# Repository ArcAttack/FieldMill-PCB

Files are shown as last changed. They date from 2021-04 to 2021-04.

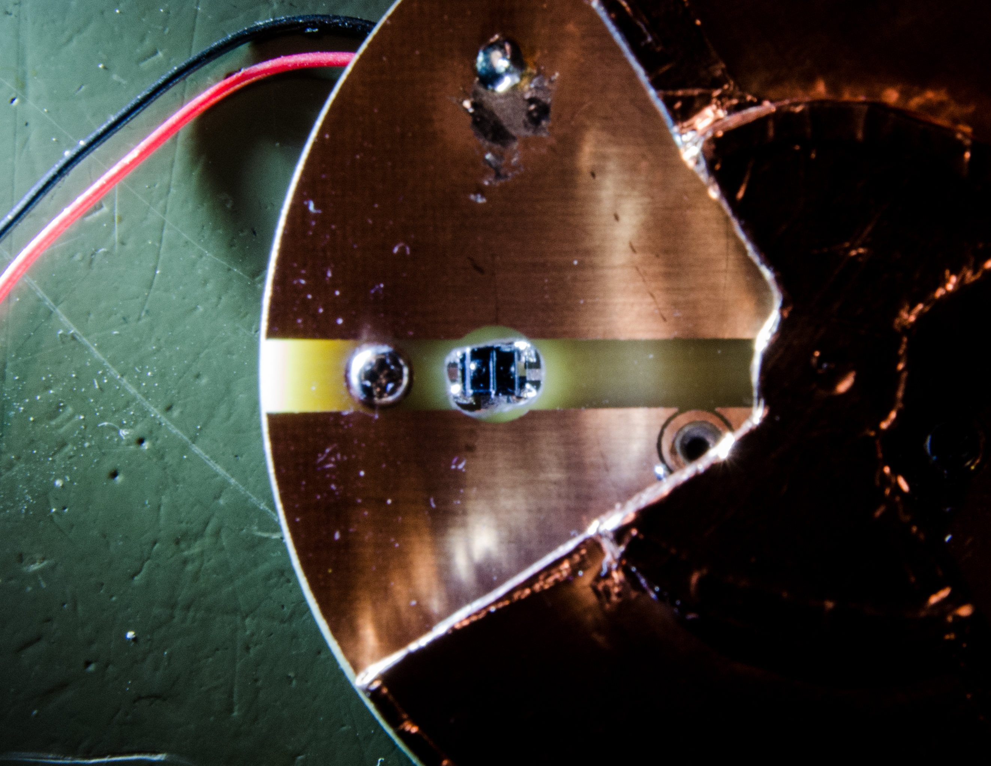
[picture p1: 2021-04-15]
Pictures/Image-4.jpg

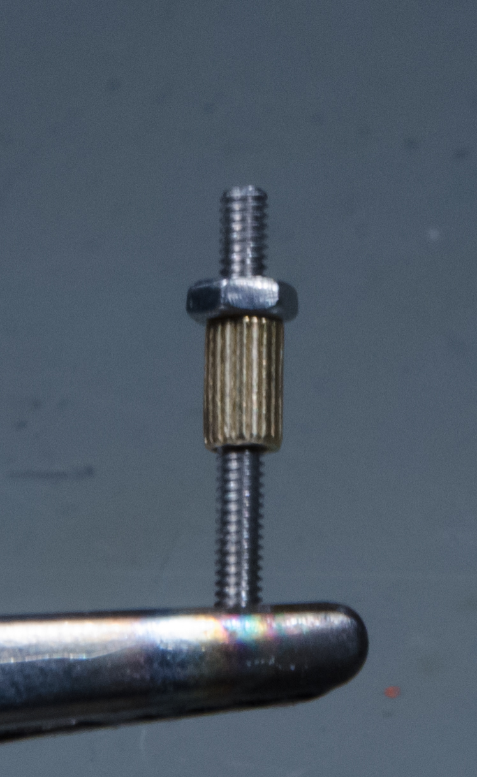
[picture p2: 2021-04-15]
Pictures/Image-7.jpg

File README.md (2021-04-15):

# FieldMill PCB Files
This is the Repo for the hardware associated with our Fieldmill project [link TBD]

# A short guide of how to make one yourself
### Component procurement. You'll need the following:

  - The PCBs: 
   
    There are exported gerbers packaged into .rar archives in the Gerber/V[number] folder, all four are needed. You can order these from whatever PCB manufacturer you prefer or make them yourself
    They are all single layer* and I have made the demo mill with home-etched pcbs too.
    (JLC would charge ~11€ plus shipping for all required PCBs as of April 2021)
    
    *The stator and rotor are double layer but have no structures on the bottom one. The rotor just needs to be cut from double sided base material. The stator boards needs to have the holes connecting the four electrodes (the ones that are in the middle of them) slightly counter-sunk on the bottom side to prevent shorting against the back plane.
    
  - The Components: 
  
    You will need approximately 25€ worth of components. Almost all smd parts, but non smaller than 0805. 
    I have created a ready to import bom document for DigiKey ("Full BOM - DigiKey.xlsx"). Simply import it to your card with the "Upload a File" Tab above the manual part adding box on the top of the page. You can ignore the warning about better options and just hit the submit button if it warns you about that.
    
    __IMPORTANT__ the ESP32 dev kit is not included in the BOM, you will need to find it somewhere else. Doesn't need to be anything special and you'll probably find it on any of the common websites (aliexpress, amazon, ebay...)
    You will also need a set of M2 (or comparable imperial size) standoffs and screws (four a few mm long plus four >20mm ones that get cut apart) to mount the boards together, I used some from a multi box set from amazon but anything that is kind of the right size will work.
    
### Assembly.

1.  Assemble the individual PCBs. (check out the Pictures folder for some reference images showing how it should look and which side the components go onto)
    
    If you have never soldered SMD parts before I recommend watching some of the how to videos about it on youtube. Don't worry it's really not that hard :) (just remember: you can't ever have too much flux ;) )
    The component values should all be marked on the silkscreen, but if I forgot any or you made the board at home you can always look at the parts list in the PDF docs ("ESP32 Board.PDF" and "Front End.PDF")
    
    **IMPORTANT** make sure to clean the front-end board VERY THOROUGHLY with a brush and IPA or ethanol after assembly. Even the slightest residue will cause leakages that ruin the Sensor
   
2.  Prepare the case. 

    The STL files for this are in the "3D Models" Folder. There are four pieces that need to be made. The precision does not need to be very high (I had a friend print this on a 5 year old filament printer with no issues).
    If the screw threads on the middle part don't quite work out you can use a bit of sand paper or a file to get them to fit.
    
    Then you will need to cover the top part (the one that has no closed ends) in copper tape or something else conductive to prevent charges building up on it and ruining the readings. 
    You will also need to cover one half of the middle part, specifically the one where the sensor fits. To figure out which one that is you should check on which side the header on the front end board lines up with the hole in hte center part. 
    
    After you've done that you should screw the top and middle parts together (maybe even glue them with a bit of CA glue) and tape across the gap on the inside to electrically connect them (make sure you test this with a multimeter!). (It should look like Image-2.jpg after this)
    
3.  Assemble the sensor. (to see on which side things should go look at Image-5.jpg)

    Start off by screwing the motor and four male-female 5mm standoffs to the stator board (the standoffs go into the four outer holes). The parts all go onto the side that has the exposed pad in the middle.
    
    Then solder some single header pins onto the pads facing the same diretion as the motor does, and push the front end board onto it. The 8 pin header on it should face away from the stator.
    **IMPORTANT** make sure that the optical sensor (IC2) is located underneath the slot in the stator board (as Image-4.jpg shows) or the mill will not work!
    
    Next you can solder the pins to the front end board (make sure it is sitting flat), and screw some female-female 10mm standoffs onto the threads of the standoffs from the previos step to hold the PCB in place.
    
    To screw the assembly into the case you need to cut 20mm pieces off of an M2 threaded rod (or a long screw) and screw them through some female-female 5mm standoffs (compare Image-7.jpg, the nut is to allow screwing it in with a screwdriver). It should go inside the copper coverd side of the case we made before.
    Before you screw it in you should make sure that the motor wires are pulled through the hole in the center part and pin header on the front end board is located over it (as in Image-6.jpg) so the ESP board can be connected to it in the next step. 
    
    Now you need to ground the motor shaft, which we do with the spring pluger. If your screw take solder you can just solder it right onto them like you see in Picture-5.jpg. If they don't you can take a male-female standoff and use a file or some rough sandpaper to make it ~0.5mm tall and then solder onto that (thats the way I did it). I also used a triangular file to cut a little vertical groove into the plunger to give it some larger contact area, but I'm not sure if that really does much. You might also want to add a tiny dab of lithium grease to the shaft after this to reduce friction and wear.
    
    We also need to make the rotor. To mount it on the shaft and electrically connect the two you'll need the hub from the 3D Models folder: solder a ~0.4mm wire into the small off-center hole on the rotor, pull it through the hub and glue the hub down onto the rotor PCB. Make sure that you orient the hub so the wire can go into the little groove in the side of it. Just press fit it onto the shaft and make sure it is sitting sort of square (best seen when looking at it from the side and turning it).
    
    **IMPORTANT** If you made these boards yourself or you ordered them with gold plating you might need to cover the bottom of the Rotor (the exposed side) with aluminium tape, as the opto-interrupter might not get enough signal otherwise.
    
    Finally you have to push the ESP32 board onto the back of what we just made (should look like Image-9.jpg), so it connects with the pins on the front end, and screw it on with either some more f-f m2 standoffs (no longer than 10mm though) or just some m2 washers. You might have to cut the pin header down a bit though, the one I found on digikey is not the same lengh as the one I used.
    To access the USB port you'll need to leave the bottom cover off, but once the code is programmed you can close that and only need access to the power input, which should line up with the hole in the side.
    
### Software 
  
  To programm the ESP you should follow the steps detailed in the firmware repo: https://github.com/ArcAttack/FieldMill-Firmware
  
### Profit
    
That's it :) If you have any questions feel free to contact us on our website and we look forward to hearing your feedback.
    
# Notes

VIn needs to be between 6V and 24V, the mill can also run from just USB.

To connect the motor you can either solder in the wire directly or use some JST XH connectors. You can buy those in kits too, just look for XH connector set on the internet and you'll find them. The wires from the motor are so small that you might have to solder them into the crimp-contacts though.

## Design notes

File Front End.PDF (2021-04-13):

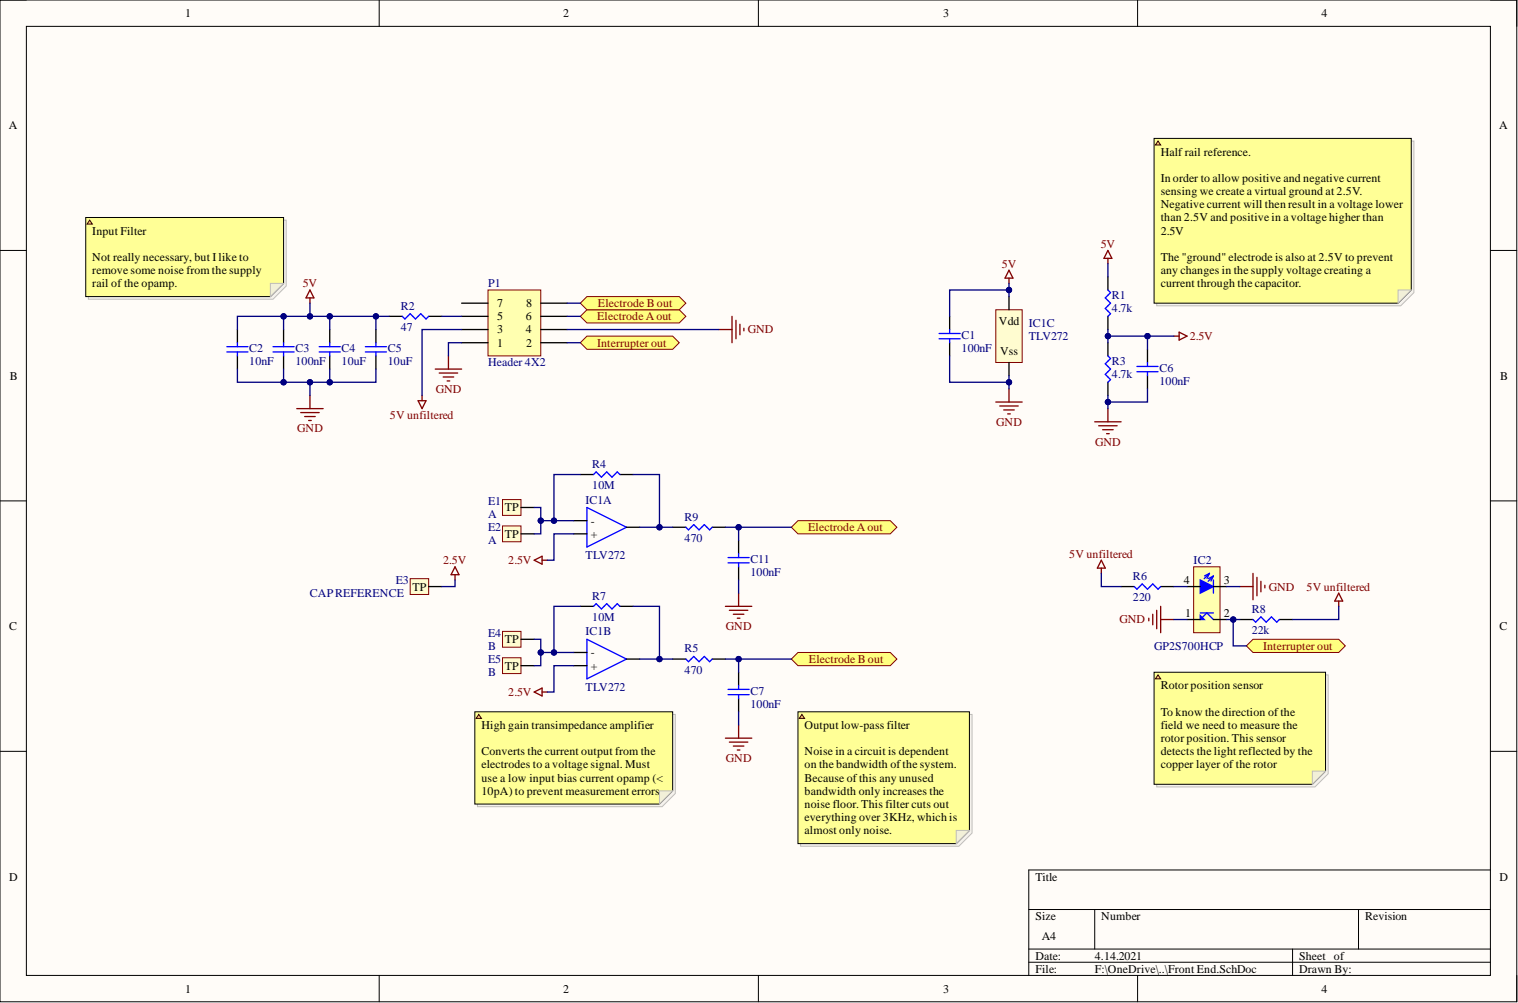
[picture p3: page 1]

Line # | Name | Description | Designator | Quantity | TargetPrice | Manufacturer 1 | Manufacturer Part Number 1 | Manufacturer Lifecycle 1 | Supplier 1 | Supplier Part Number 1 | Supplier Unit Price 1 | Supplier Subtotal 1
| 100nF | | C1, C3, C6, C7, C11 | 5 | 0 KEMET | | C0402C104K8PACTU | Volume Production | Digi-Key | 399-3027-1-ND | 0,042 | 0,42
| 10nF | | C2 | 1 | 0 Samsung | | CL21B103KBANNNC | Volume Production | Digi-Key | 1276-1015-1-ND | 0,1 | 0,1
| 10uF | | C4, C5 | 2 | 0 Murata | | GRM188R60J106ME47D | Volume Production | Digi-Key | 490-3896-1-ND | 0,25 | 0,5
| A | | E1, E2 | 2 | 0
| CAP REFERENCE | | E3 | 1 | 0
| B | | E4, E5 | 2 | 0
| TLV272 | | IC1 | 1 | 0,99 Texas Instruments | | TLV272IDR | Volume Production | Digi-Key | 296-10655-1-ND | 0,99 | 0,99
| 4.7k | | R1, R3 | 2 | 0 Yageo | | RT0805FRE074K7L | Not Recommended for New Design | Digi-Key | YAG3364CT-ND | 0,1 | 0,2
| 47 | | R2 | 1 | 0 Yageo | | RC0805JR-0747RL | Volume Production | Digi-Key | 311-47ARCT-ND | 0,1 | 0,1
| 10M | | R4, R7 | 2 | 0 Yageo | | RC0805JR-0710ML | Volume Production | Digi-Key | 311-10MARCT-ND | 0,1 | 0,2
| 470 | | R5, R9 | 2 | 0 Yageo | | RC0805JR-07470RL | Volume Production | Digi-Key | 311-470ARCT-ND | 0,1 | 0,2
| 220 | | R6 | 1 | 0 Yageo | | RC0805FR-07220RL | Volume Production | Digi-Key | 311-220CRCT-ND | 0,1 | 0,1
| 22k | | R8 | 1 | 0 Yageo | | RC0805FR-0722KL | Volume Production | Digi-Key | 311-22.0KCRCT-ND | 0,1 | 0,1
| Header 4X2 | Header, 4-Pin, Dual row | P1 | 1 | 0
| GP2S700HCP | Optical reflection interrupter | IC2 | 1 | 0 Socle Technology | | GP2S700HCP | Unknown | Digi-Key | 1855-1020-1-ND | 1,71 | 1,71

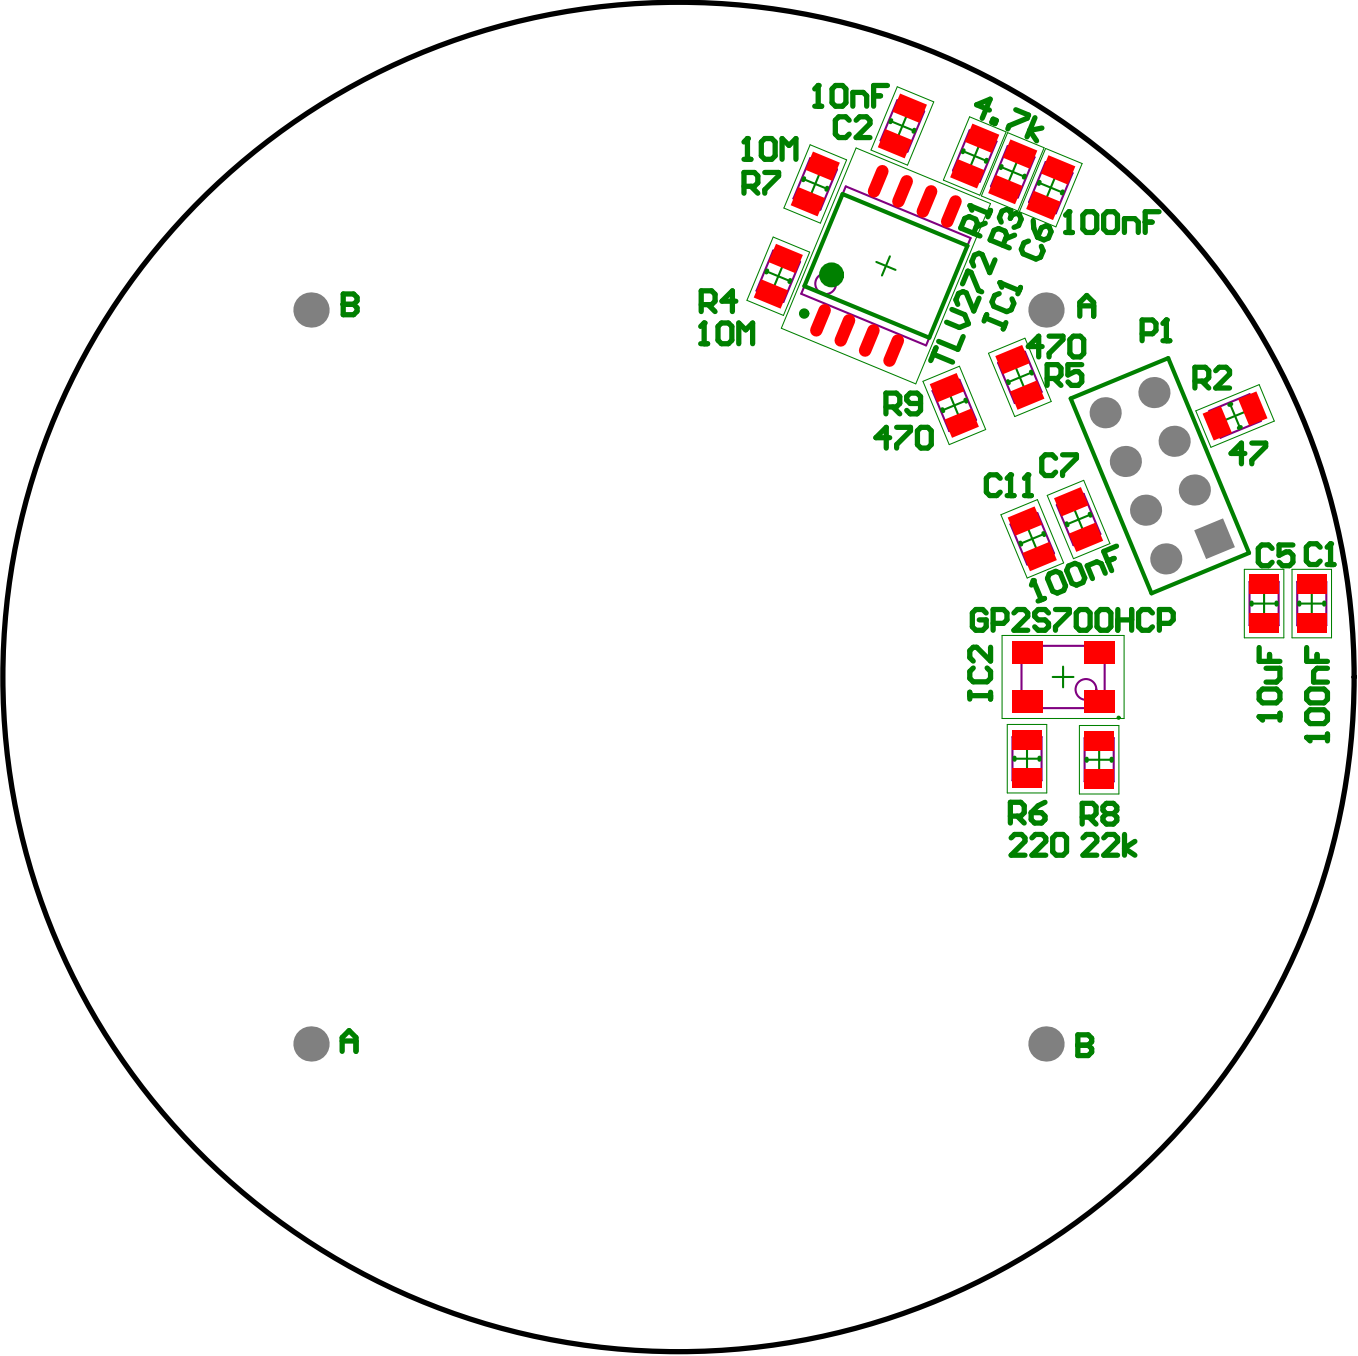
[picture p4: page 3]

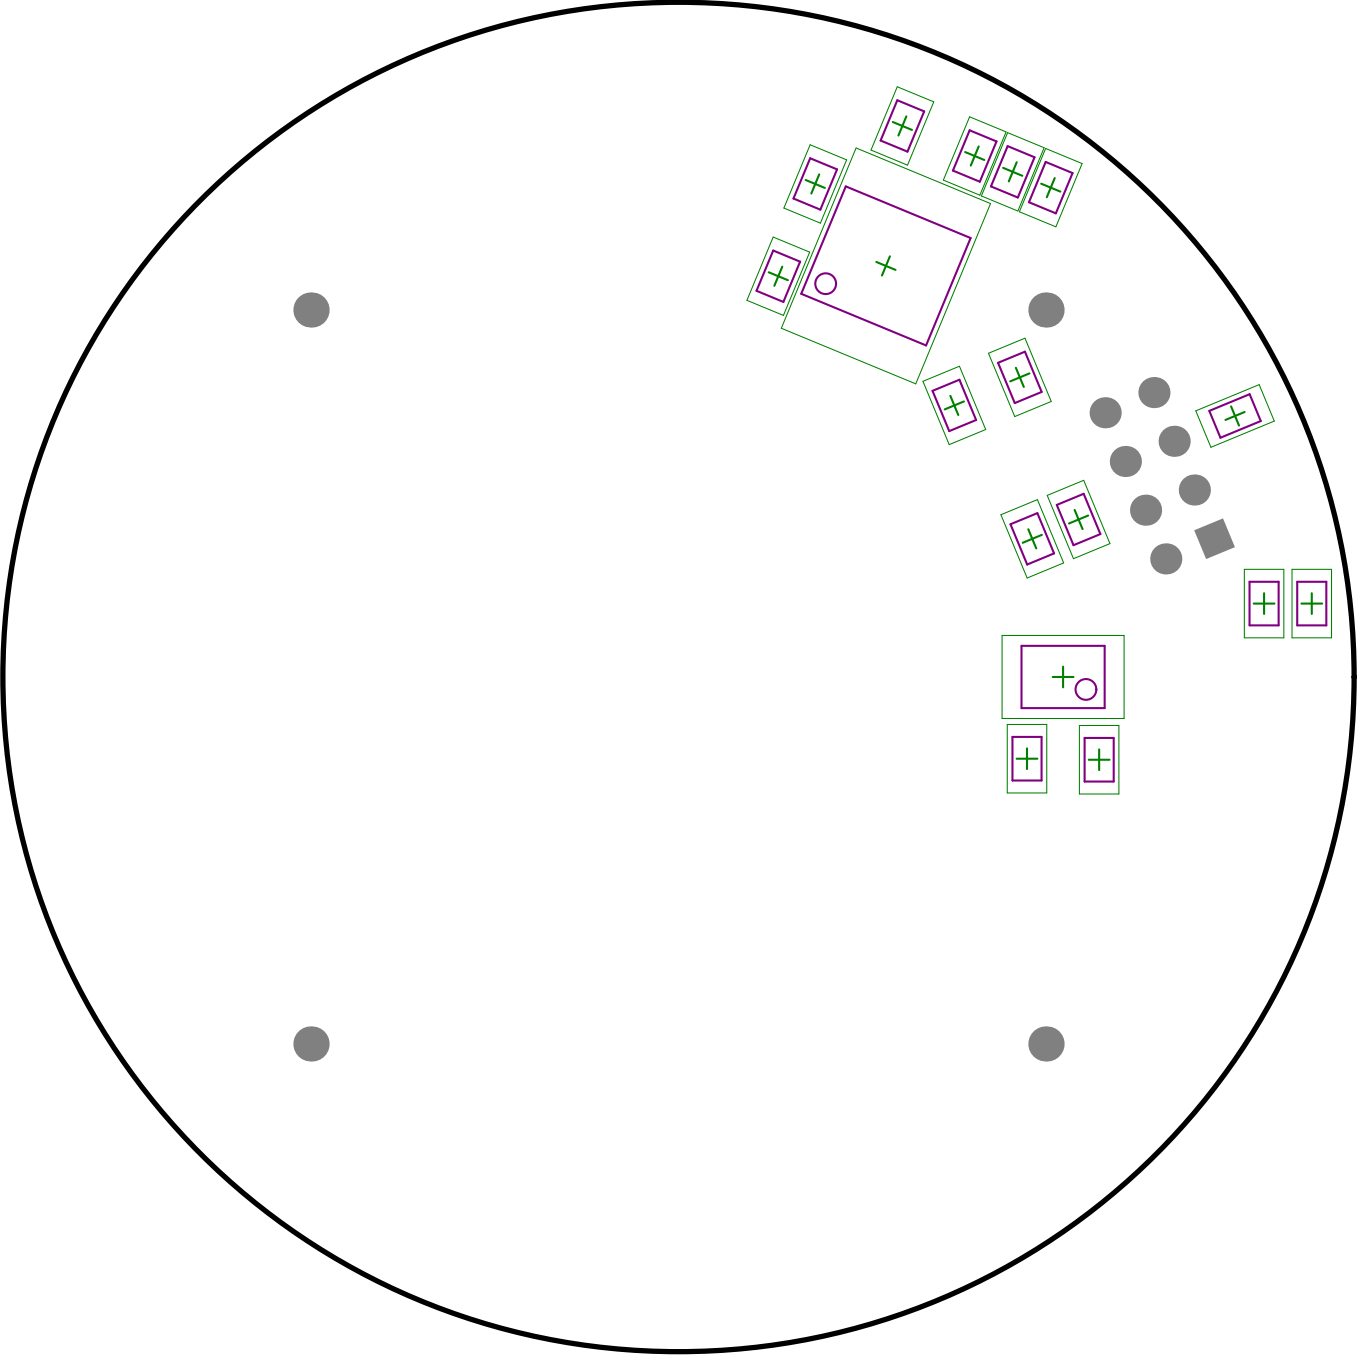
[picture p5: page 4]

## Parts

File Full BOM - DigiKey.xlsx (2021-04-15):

Manufacturer Part Number | Manufacturer | Digi-Key Part Number | Customer Reference | Reference Designator | Packaging | Part Status | Quantity | Unit Price | Extended Price | Quantity Available | Mfg Std Lead Time | Description | RoHS Status | Lead Free Status | REACH Status
CL21B104KACNNNC | Samsung Electro-Mechanics | 1276-1099-1-ND |  |  | Cut Tape (CT) | Active | 6 | 0,09000 | 0,54 € | 278128 | 28 Weeks | CAP CER 0.1UF 25V X7R 0805 | ROHS3 Compliant | Lead free | REACH Unaffected
ESH337M035AH1AA | KEMET | 399-6581-ND |  |  | Bulk | Active | 1 | 0,35000 | 0,35 € | 3671 | 24 Weeks | CAP ALUM 330UF 20% 35V RADIAL | ROHS3 Compliant | Lead free | REACH Unaffected
CL21B102KBANNNC | Samsung Electro-Mechanics | 1276-1020-1-ND |  |  | Cut Tape (CT) | Active | 2 | 0,09000 | 0,18 € | 313296 | 28 Weeks | CAP CER 1000PF 50V X7R 0805 | ROHS3 Compliant | Lead free | REACH Unaffected
CL21A106KAYNNNG | Samsung Electro-Mechanics | 1276-6454-1-ND |  |  | Cut Tape (CT) | Active | 2 | 0,18000 | 0,36 € | 277384 | 28 Weeks | CAP CER 10UF 25V X5R 0805 | ROHS3 Compliant | Lead free | REACH Unaffected
B130-13-F | Diodes Incorporated | B130-FDICT-ND |  |  | Cut Tape (CT) | Active | 3 | 0,31000 | 0,93 € | 148532 | 18 Weeks | DIODE SCHOTTKY 30V 1A SMA | ROHS3 Compliant | Contains lead | REACH Affected
LG R971-KN-1 | OSRAM Opto Semiconductors Inc. | 475-1410-1-ND |  |  | Cut Tape (CT) | Active | 1 | 0,22000 | 0,22 € | 324582 | 12 Weeks | LED GREEN DIFFUSED 0805 SMD | ROHS3 Compliant | Lead free | REACH Unaffected
150060GS75000 | Würth Elektronik | 732-4971-1-ND |  |  | Cut Tape (CT) | Active | 3 | 0,12000 | 0,36 € | 93911 | 10 Weeks | LED GREEN CLEAR 0603 SMD | ROHS3 Compliant | Lead free | REACH Unaffected
ADR02ARZ | Analog Devices Inc. | ADR02ARZ-ND |  |  | Tube | Active | 1 | 2,58000 | 2,58 € | 1936 | 28 Weeks | IC VREF SERIES 0.1% 8SOIC | ROHS3 Compliant | Lead free | REACH Unaffected
MCP3301-BI/SN | Microchip Technology | MCP3301-BI/SN-ND |  |  | Tube | Active | 1 | 2,49000 | 2,49 € | 2419 | 45 Weeks | IC ADC 13BIT SAR 8SOIC | ROHS3 Compliant | Lead free | REACH Unaffected
PJ-082BH | CUI Devices | CP-082BHCT-ND |  |  | Cut Tape (CT) | Active | 1 | 1,46000 | 1,46 € | 27481 | 11 Weeks | CONN PWR JACK 2.5X5.5MM SOLDER | RoHS Compliant | Lead free | Not Available
LQH43PN470M26L | Murata Electronics | 490-12050-1-ND |  |  | Cut Tape (CT) | Active | 1 | 0,34000 | 0,34 € | 4114 | 19 Weeks | FIXED IND 47UH 520MA 861.6 MOHM | ROHS3 Compliant | Lead free | Not Available
2546 | Kitronik Ltd. | 1927-1023-ND |  |  | Bag | Active | 1 | 1,35000 | 1,35 € | 88 | 4 Weeks | MOTOR LO INERTIA 1820 RPM 0.5-3V | Not Available | Not Available | Not Available
T2N7002AK,LM | Toshiba Semiconductor and Storage | T2N7002AKLMCT-ND |  |  | Cut Tape (CT) | Active | 1 | 0,14000 | 0,14 € | 28842 | 16 Weeks | MOSFET N-CH 60V 200MA SOT23 | RoHS Compliant | Lead free | Not Available
RC0805JR-072K2L | Yageo | 311-2.2KARCT-ND |  |  | Cut Tape (CT) | Active | 1 | 0,09000 | 0,09 € | 103703 | 20 Weeks | RES SMD 2.2K OHM 5% 1/8W 0805 | ROHS3 Compliant | Lead free | REACH Unaffected
RT0805FRE074K7L | Yageo | YAG3364CT-ND |  |  | Cut Tape (CT) | Active | 3 | 0,09000 | 0,27 € | 14055 | 20 Weeks | RES SMD 4.7K OHM 1% 1/8W 0805 | ROHS3 Compliant | Lead free | REACH Unaffected
RC0805FR-07220RL | Yageo | 311-220CRCT-ND |  |  | Cut Tape (CT) | Active | 5 | 0,09000 | 0,45 € | 61879 | 20 Weeks | RES SMD 220 OHM 1% 1/8W 0805 | ROHS3 Compliant | Lead free | REACH Unaffected
RC0805FR-07100RL | Yageo | 311-100CRCT-ND |  |  | Cut Tape (CT) | Active | 1 | 0,09000 | 0,09 € | 2632504 | 20 Weeks | RES SMD 100 OHM 1% 1/8W 0805 | ROHS3 Compliant | Lead free | REACH Unaffected
RC0805FR-071KP | Yageo | YAG1321DKR-ND |  |  | Digi-Reel | Active | 1 | 5,59000 | 5,59 € | 19807 | 20 Weeks | RES SMD 1K OHM 1% 1/8W 0805 | ROHS3 Compliant | Lead free | REACH Unaffected
RC0805JR-071K2L | Yageo | 311-1.2KARDKR-ND |  |  | Digi-Reel | Active | 1 | 5,59000 | 5,59 € | 446839 | 20 Weeks | RES SMD 1.2K OHM 5% 1/8W 0805 | ROHS3 Compliant | Lead free | REACH Unaffected
RC0805JR-07300RL | Yageo | 311-300ARCT-ND |  |  | Cut Tape (CT) | Active | 1 | 0,09000 | 0,09 € | 258469 | 20 Weeks | RES SMD 300 OHM 5% 1/8W 0805 | ROHS3 Compliant | Lead free | REACH Unaffected
AP1509-50SG-13 | Diodes Incorporated | AP1509-50SGDICT-ND |  |  | Cut Tape (CT) | Active | 1 | 1,18000 | 1,18 € | 10541 | 36 Weeks | IC REG BUCK 5V 2A 8SOP | ROHS3 Compliant | Lead free | REACH Unaffected
C0402C104K8PACTU | KEMET | 399-3027-1-ND |  |  | Cut Tape (CT) | Active | 5 | 0,09000 | 0,45 € | 1668876 | 37 Weeks | CAP CER 0.1UF 10V X5R 0402 | ROHS3 Compliant | Lead free | REACH Unaffected
CL21B103KBANNNC | Samsung Electro-Mechanics | 1276-1015-1-ND |  |  | Cut Tape (CT) | Active | 3 | 0,09000 | 0,27 € | 989993 | 28 Weeks | CAP CER 10000PF 50V X7R 0805 | ROHS3 Compliant | Lead free | REACH Unaffected
GRM188R60J106ME47D | Murata Electronics | 490-3896-1-ND |  |  | Cut Tape (CT) | Active | 2 | 0,21000 | 0,42 € | 138681 | 23 Weeks | CAP CER 10UF 6.3V X5R 0603 | ROHS3 Compliant | Lead free | Not Available
TLV272IDR | Texas Instruments | 296-10655-1-ND |  |  | Cut Tape (CT) | Active | 1 | 0,84000 | 0,84 € | 0 | 35 Weeks | IC CMOS 2 CIRCUIT 8SOIC | ROHS3 Compliant | Lead free | REACH Unaffected
GP2S700HCP | SHARP/Socle Technology | 1855-1020-1-ND |  |  | Cut Tape (CT) | Active | 1 | 1,46000 | 1,46 € | 0 | 19 Weeks | PHOTOINTERRUPTER REFLEC 3MM SMD | RoHS Compliant | Lead free | Not Available
RC0805JR-0747RL | Yageo | 311-47ARCT-ND |  |  | Cut Tape (CT) | Active | 1 | 0,09000 | 0,09 € | 353024 | 20 Weeks | RES SMD 47 OHM 5% 1/8W 0805 | ROHS3 Compliant | Lead free | REACH Unaffected
RC0805JR-0710ML | Yageo | 311-10MARCT-ND |  |  | Cut Tape (CT) | Active | 2 | 0,09000 | 0,18 € | 138592 | 20 Weeks | RES SMD 10M OHM 5% 1/8W 0805 | ROHS3 Compliant | Lead free | REACH Unaffected
RC0805JR-07470RL | Yageo | 311-470ARCT-ND |  |  | Cut Tape (CT) | Active | 2 | 0,09000 | 0,18 € | 602154 | 20 Weeks | RES SMD 470 OHM 5% 1/8W 0805 | ROHS3 Compliant | Lead free | REACH Unaffected
RC0805FR-0722KL | Yageo | 311-22.0KCRCT-ND |  |  | Cut Tape (CT) | Active | 1 | 0,09000 | 0,09 € | 460924 | 20 Weeks | RES SMD 22K OHM 1% 1/8W 0805 | ROHS3 Compliant | Lead free | REACH Unaffected
SSW-104-01-G-D | Samtec Inc. | SAM1208-04-ND |  |  | Bulk | Active | 1 | 1,16000 | 1,16 € | 2795 | 2 Weeks | CONN RCPT 8POS 0.1 GOLD PCB | ROHS3 Compliant | Lead free | REACH Unaffected
TSW-104-17-G-D | Samtec Inc. | SAM1060-04-ND |  |  | Bulk | Active | 1 | 0,90000 | 0,90 € | 414 | 2 Weeks | CONN HEADER VERT 8POS 2.54MM | ROHS3 Compliant | Lead free | REACH Unaffected
PH1-10-UA | Adam Tech | 2057-PH1-10-UA-ND |  |  | Bulk | Active | 1 | 0,16000 | 0,16 € | 3460 | 9 Weeks | CONN HEADER VERT 10POS 2.54MM | ROHS3 Compliant | Lead free | REACH Unaffected
P1113CA3 | Harwin Inc. | 952-3571-ND |  |  | Bulk | Active | 1 | 2,17000 | 2,17 € | 642 | 11 Weeks | CONTACT SPRING LOADED T/H GOLD | ROHS3 Compliant | Lead free | REACH Unaffected

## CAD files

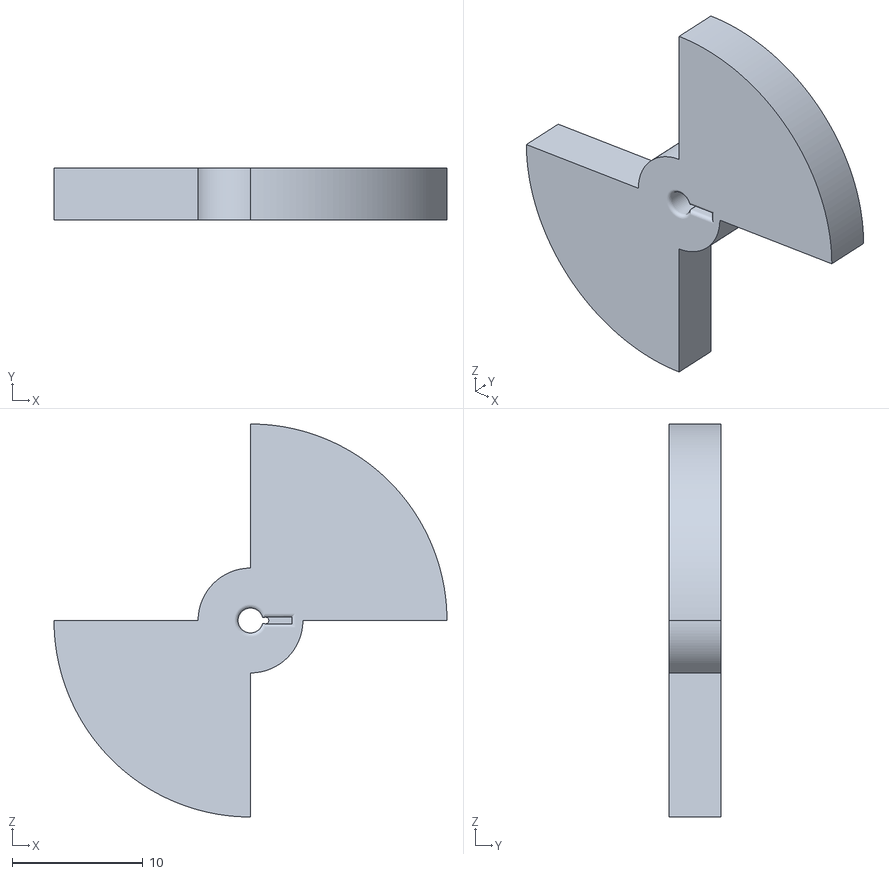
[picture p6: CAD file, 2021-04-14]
3D Models/Hub.stl
30.0 x 4.00 x 30.0

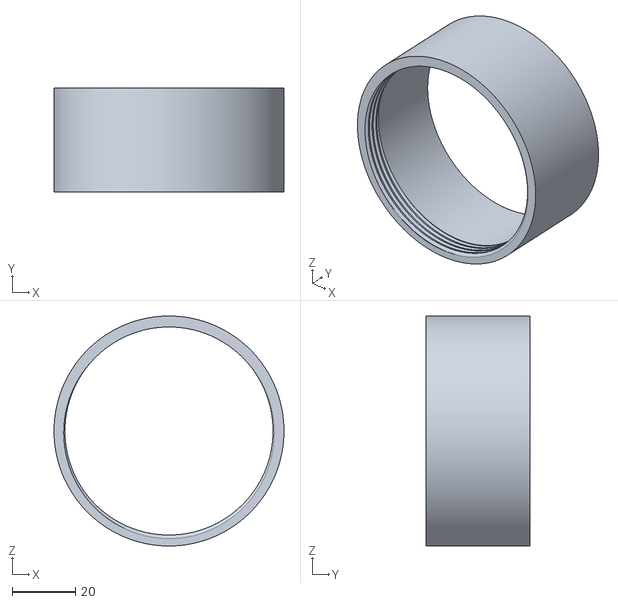
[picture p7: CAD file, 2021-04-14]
3D Models/Top.stl
73.0 x 33.0 x 73.0

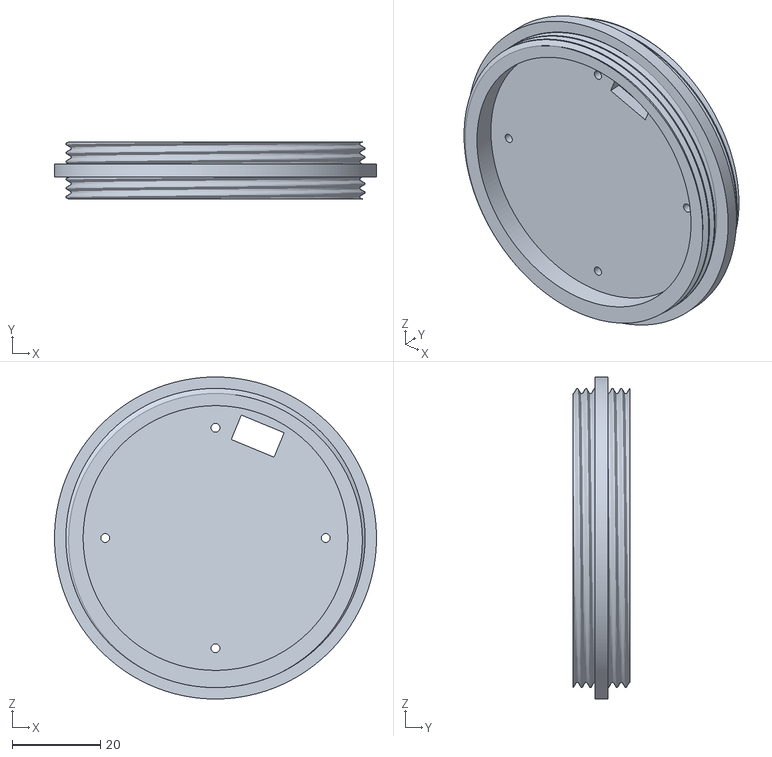
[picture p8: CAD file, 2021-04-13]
3D Models/Middle.stl
73.0 x 13.0 x 73.0

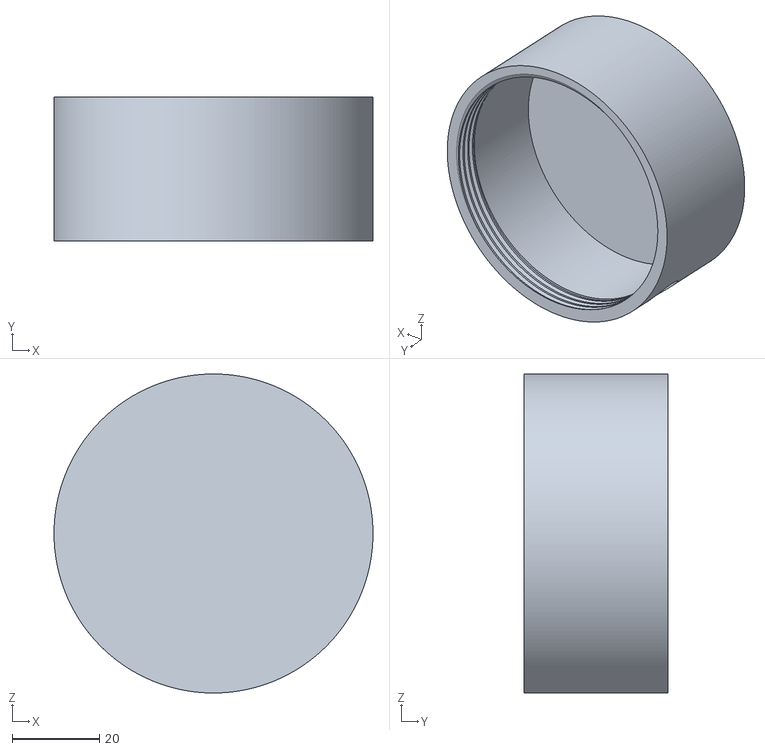
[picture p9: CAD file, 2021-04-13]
3D Models/Bottom.stl
73.0 x 33.0 x 73.0

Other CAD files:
3D Models/Mill case.f3d

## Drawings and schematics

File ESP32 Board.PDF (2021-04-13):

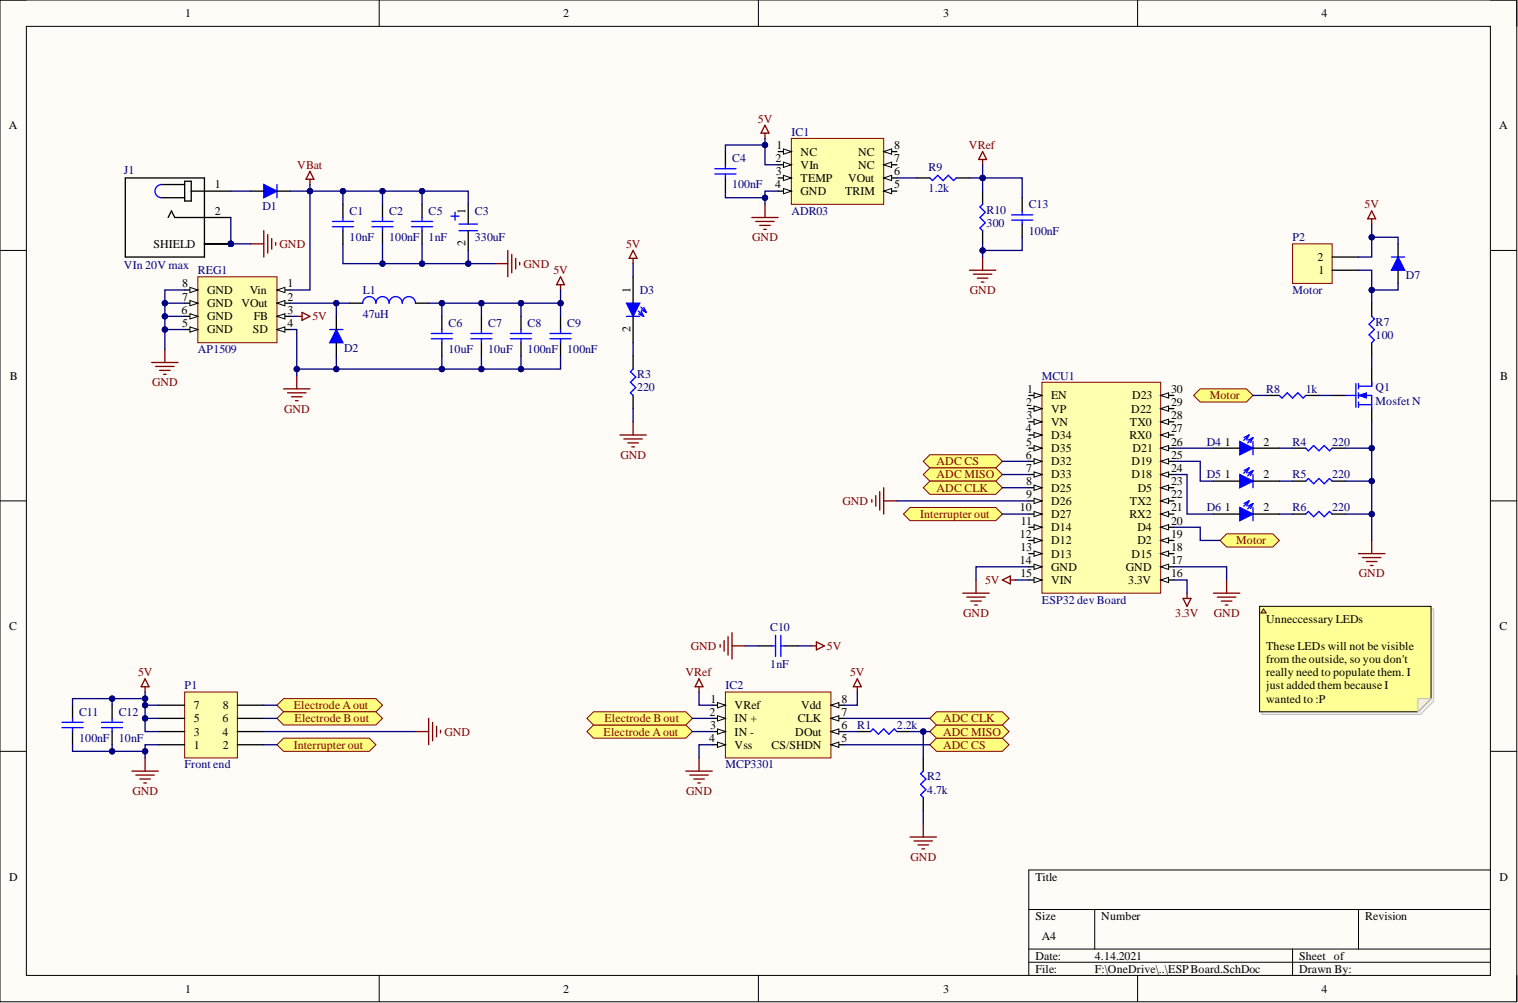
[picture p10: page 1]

These LEDs will not be visible
from the outside, so you don't
really need to populate them. I
just added them because I
wanted to :P

Line # | Name | Description | Designator | Quantity | Manufacturer 1 | Manufacturer Part Number 1 | Manufacturer Lifecycle 1 | Supplier 1 | Supplier Part Number 1 | Supplier Unit Price 1 | Supplier Subtotal 1
| 10nF | | C1, C12 | 2 Samsung | | CL21B103KBANNNC | Volume Production | Digi-Key | 1276-1015-1-ND | 0,1 | 0,2
| 100nF | | C2, C4, C8, C9, C11, C13 | 6 Samsung | | CL21B104KACNNNC | Volume Production | Digi-Key | 1276-1099-1-ND | 0,041 | 0,41
| 330uF | | C3 | 1 KEMET | | ESH337M035AH1AA | Volume Production | Digi-Key | 399-6581-ND | 0,41 | 0,41
| 1nF | | C5, C10 | 2 Samsung | | CL21B102KBANNNC | Volume Production | Digi-Key | 1276-1020-1-ND | 0,1 | 0,2
| 10uF | | C6, C7 | 2 Samsung | | CL21A106KAYNNNG | Volume Production | Digi-Key | 1276-6454-1-ND | 0,21 | 0,42
| Diode | Cmon its a diode what more do I need to say? | D1, D2, D7 | 3 Diodes | | B130-13-F | Volume Production | Digi-Key | B130-FDICT-ND | 0,36 | 1,08
| Power | | D3 | 1 Osram Opto | | LGR971-KN-1 | Volume Production | Digi-Key | 475-1410-1-ND | 0,26 | 0,26
| NOP | | D4, D5, D6 | 3 Wurth Electronics | | 150060GS75000 | Volume Production | Digi-Key | 732-4971-1-ND | 0,14 | 0,42
| ADR03 | Precision voltage reference 0.1% | IC1 | 1 Analog Devices | | ADR02ARZ | Volume Production | Digi-Key | ADR02ARZ-ND | 3,03 | 3,03
| MCP3301 | 13 bit differential ADC | IC2 | 1 Microchip | | MCP3301-BI/SN | Volume Production | Digi-Key | MCP3301-BI/SN-ND | 2,92 | 2,92
| VIn 20V max | | J1 | 1 CUI | | PJ-082BH | Volume Production | Digi-Key | CP-082BHCT-ND | 1,71 | 1,71
| 47uH | | L1 | 1 Murata | | LQH43PN470M26L | Volume Production | Digi-Key | 490-12050-1-ND | 0,4 | 0,4
| ESP32 dev Board | Dev board of the esp32 | MCU1 | 1
| Front end | Header, 4-Pin, Dual row | P1 | 1
| Motor | Header, 2-Pin | P2 | 1 Kitronik | | 2546 | Unknown | Digi-Key | 1927-1023-ND | 1,58 | 1,58
| Mosfet N | | Q1 | 1 Toshiba | | T2N7002AK,LM | Volume Production | Digi-Key | T2N7002AKLMCT-ND | 0,16 | 0,16
| 2.2k | | R1 | 1 Yageo | | RC0805JR-072K2L | Volume Production | Digi-Key | 311-2.2KARCT-ND | 0,1 | 0,1
| 4.7k | | R2 | 1 Yageo | | RT0805FRE074K7L | Not Recommended for New Design | Digi-Key | YAG3364CT-ND | 0,1 | 0,1
| 220 | | R3, R4, R5, R6 | 4 Yageo | | RC0805FR-07220RL | Volume Production | Digi-Key | 311-220CRCT-ND | 0,1 | 0,4
| 100 | | R7 | 1 Yageo | | RC0805FR-07100RL | Volume Production | Digi-Key | 311-100CRCT-ND | 0,1 | 0,1
| 1k | | R8 | 1 Yageo | | RC0805FR-071KP | Volume Production | Digi-Key | YAG1321DKR-ND | 0,1 | 0,1
| 1.2k | | R9 | 1 Yageo | | RC0805JR-071K2L | Volume Production | Digi-Key | 311-1.2KARDKR-ND | 0,1 | 0,1
| 300 | | R10 | 1 Yageo | | RC0805JR-07300RL | Volume Production | Digi-Key | 311-300ARCT-ND | 0,1 | 0,1
| AP1509 | Fixed voltage buck regulator | REG1 | 1 Diodes | | AP1509-50SG-13 | Volume Production | Digi-Key | AP1509-50SGDICT-ND | 1,39 | 1,39

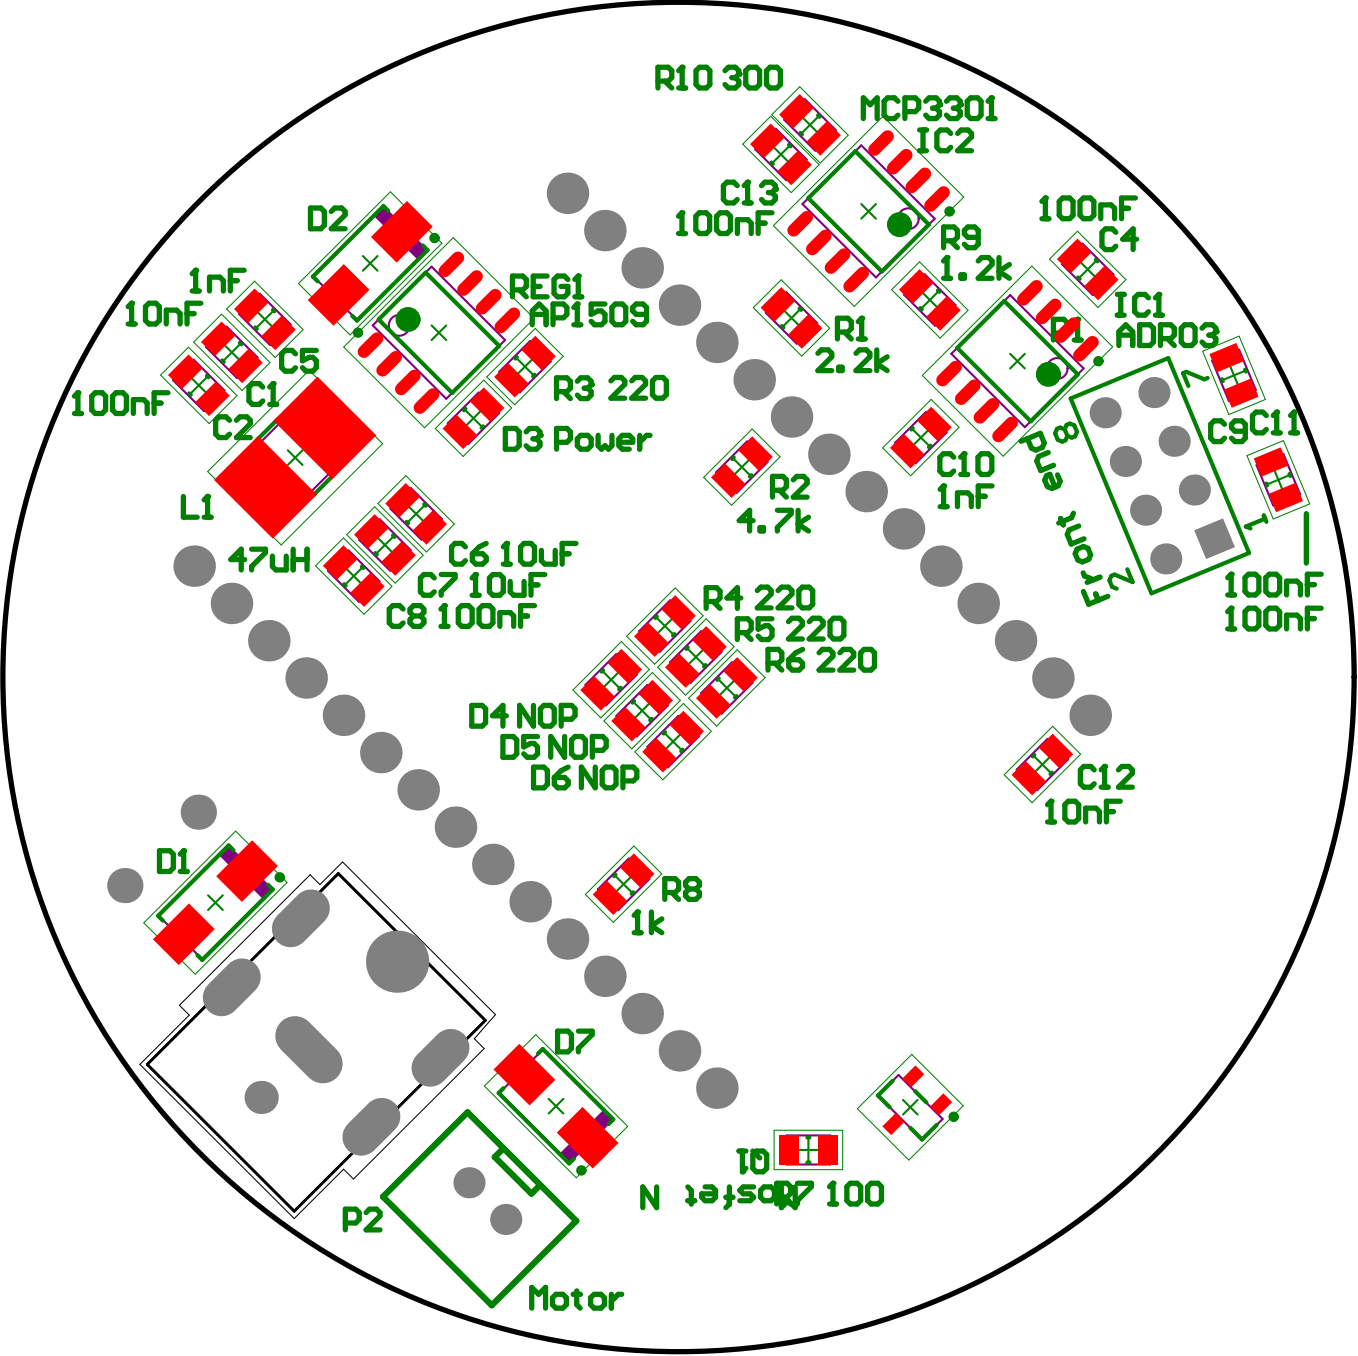
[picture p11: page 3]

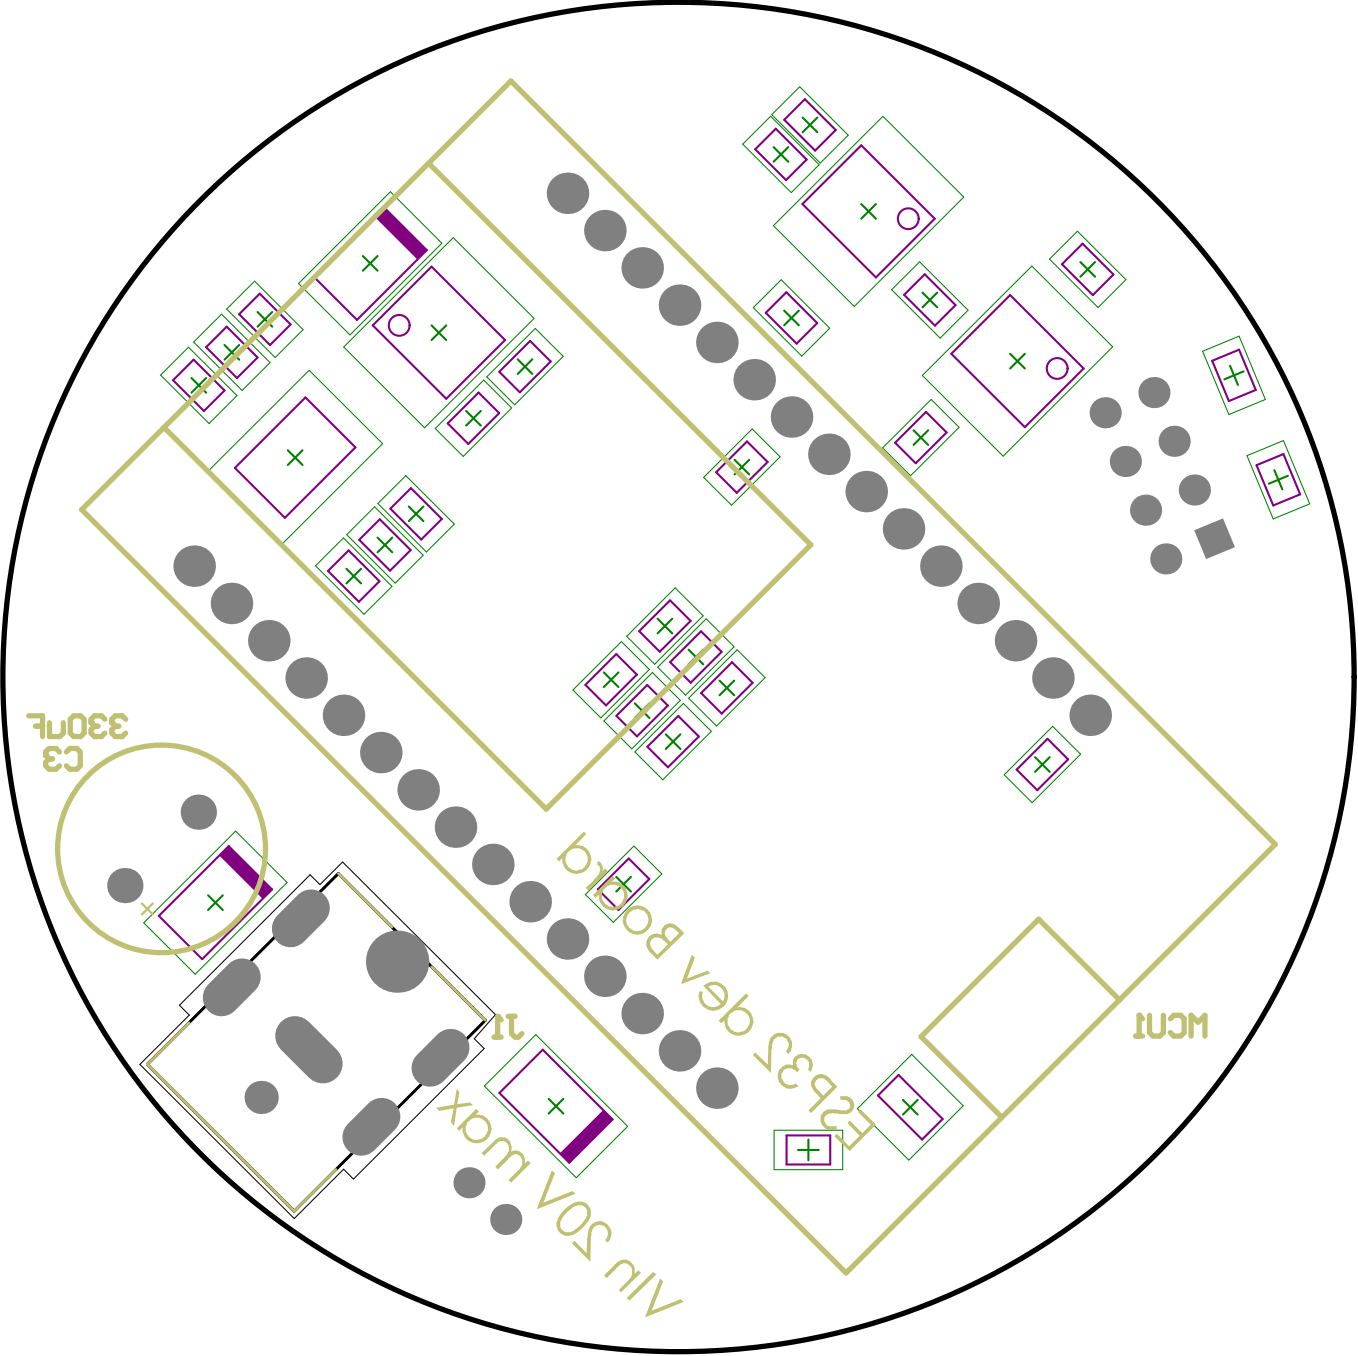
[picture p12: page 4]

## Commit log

2021-04-13 inital Commit
    [Bottom.stl, ESP Board.PcbDoc, ESP Board.SchDoc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]
2021-04-13 fixed file name typo
    [Full BOM - DigiKey.xlsx]
2021-04-14 opened lid on 3d model
    [Top.stl]
2021-04-14 Added the Hub
    [Hub.stl]
2021-04-14 added pin headers to bom
    [Full BOM - DigiKey.xlsx]
2021-04-15 Changed motor to 3.3V and updated gerbers
    [ESP Board.PcbDoc, ESP Board.SchDoc, Field Sensor ESP32.PrjPCB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]
2021-04-15 Update ESP Board.PcbDoc
    [ESP Board.PcbDoc]
2021-04-15 Added exposed bottom section on the Rotor
    [Rotor.PcbDoc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]
2021-04-15 Added spring plunger
    [Full BOM - DigiKey.xlsx]
